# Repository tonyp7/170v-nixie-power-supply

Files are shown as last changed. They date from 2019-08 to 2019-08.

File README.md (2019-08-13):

# 170v-nixie-power-supply
170V, LT3757 based nixie power supply **open source hardware**.

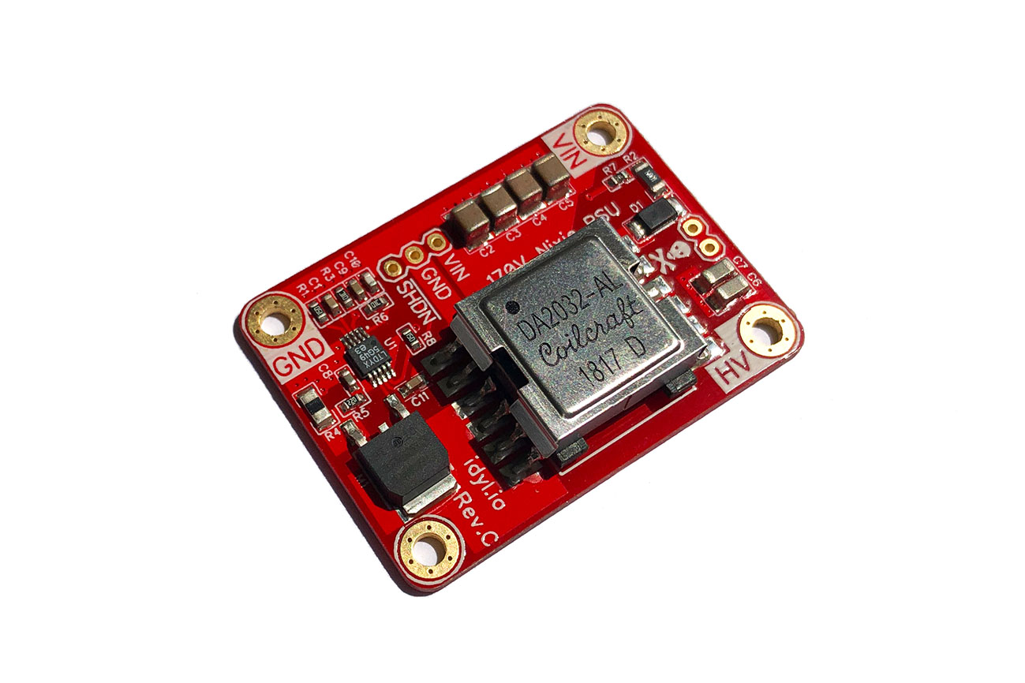
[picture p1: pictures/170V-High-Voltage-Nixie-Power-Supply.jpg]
Assembled PCB


These pages contains everything you need to create a high efficiency nixie power supply.

# Repository Structure

* bom: the bill of materials for the power supply.
* gerber: gerber to generate the PCB for the power supply, together with a render.
* pictures: just some pics of the board.
* schematics: available as png or pdf format.

# Links

* Tindie Store https://www.tindie.com/products/tonyp7/170v-high-voltage-nixie-power-supply/
* Hackaday project page https://hackaday.io/project/162301-high-voltage-nixie-power-supply
* Personal pages https://idyl.io

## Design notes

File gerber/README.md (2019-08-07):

# Gerber Files

These gerber files will allow you to create a new PCB; as shown below:

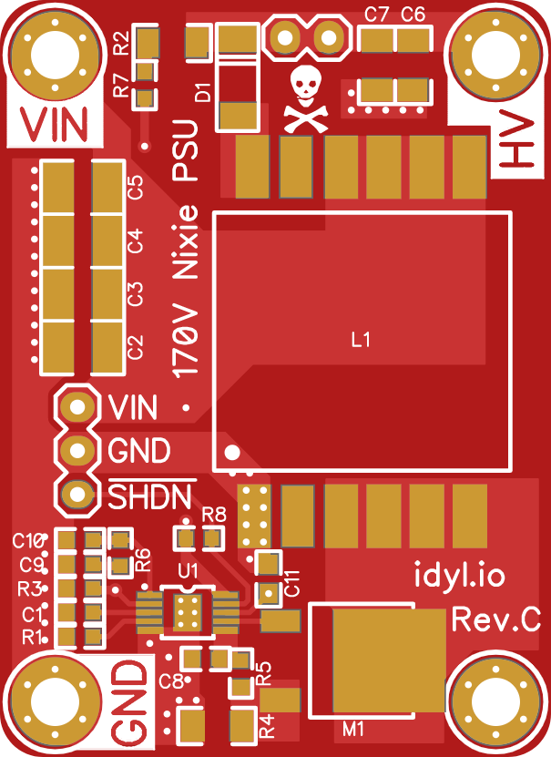
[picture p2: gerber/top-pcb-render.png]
PCB Render


Render courtesy of tracespace.io

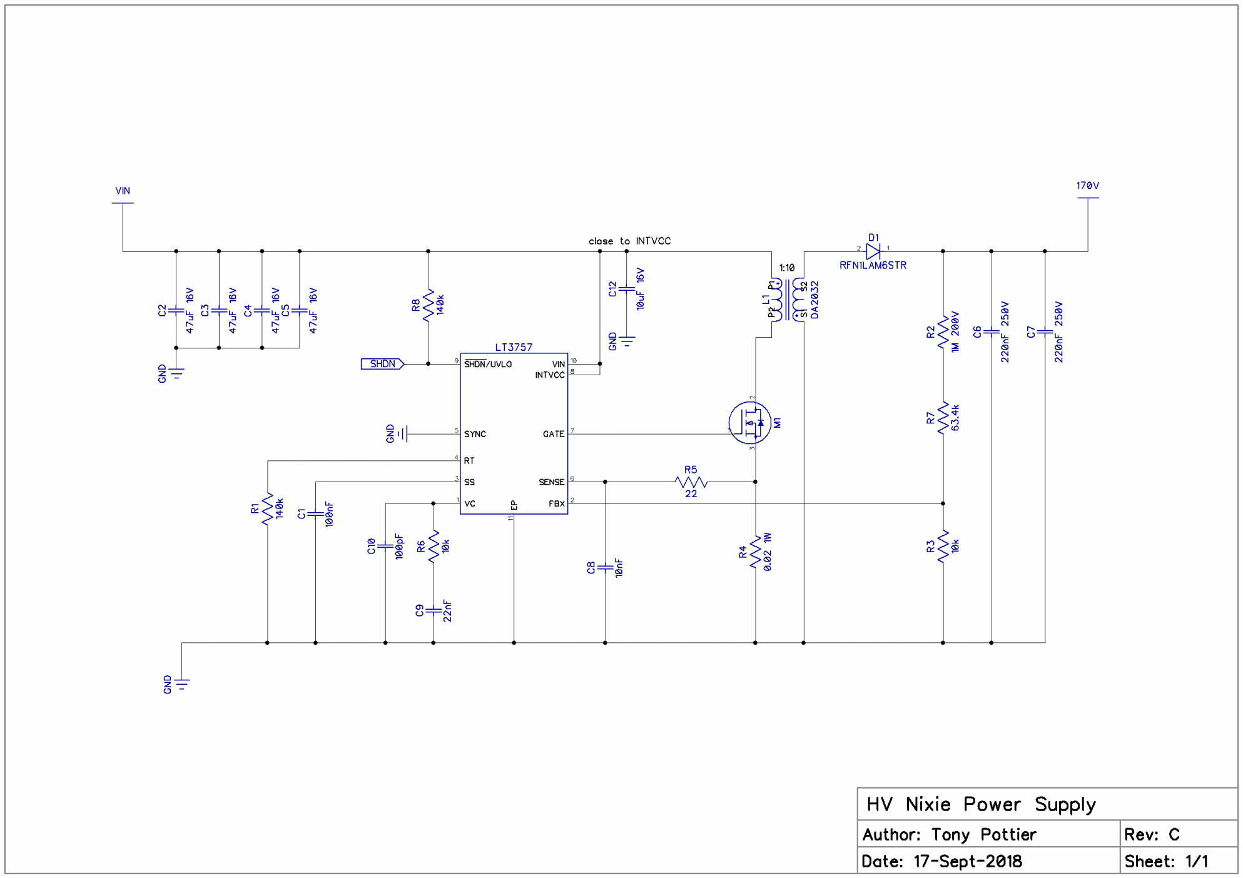
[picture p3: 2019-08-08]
schematics/lt3757-170-power-supply-schematics.png

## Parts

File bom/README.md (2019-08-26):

# Bill of Materials

In this folder you will find the BOM for the PSU, in various formats: CSV, Excel and OpenDocument Spreadsheet. Below in markdown format:

| Ref Desc | Quantity | Manufacturer | Manufacturer Part Number | Description | Package | Type | Comment |
| --- | --- | --- | --- | --- | --- | ---- | --- |
| C1 | 1 | Yageo | CC0603KRX7R9BB104 | 0.1µF ±10% 50V MLCC X7R 0603 | 0603 | SMD |  |
| C2, C3, C4, C5 | 4 | Taiyo Yuden | EMK325BJ476MM-T | 47µF ±20% 16V MLCC X5R 1210 | 1210 | SMD | Use 25V if you can to increase VIN range |
| C6, C7 | 2 | TDK | C3216X7T2E224K160AA | 0.22µF ±10% 250V MLCC X7T 1206 | 1206 | SMD | Must be 250V+ rated |
| C8 | 1 | Yageo | AC0603KRX7R9BB103 | 0.01µF ±10% 50V MLCC X7R 0603 | 0603 | SMD |  |
| C9 | 1 | Yageo | CC0603KRX7R9BB223 | 0.022µF ±10% 50V MLCC X7R 0603 | 0603 | SMD |  |
| C10 | 1 | Yageo | CC0603KRX7R9BB101 | 100pF ±10% 50V MLCC X7R 0603 | 0603 | SMD |  |
| C11 | 1 | Yageo | CC0603MRX5R7BB106 | 10µF ±20% 16V MLCC X5R 0603 | 0603 | SMD |  |
| D1 | 1 | ROHM | RFN1LAM6STR | Diodes - General Purpose, Power, Switching 600V VR 0.8A IO SOD-128; PMDTM | SOD128 | SMD | ES1G works well if you'd like a more commonly available part |
| L1 | 1 | Coilcraft | DA2032-ALB | Flyback Transformer 1:10 10uH | DA2032 | SMD |  |
| M1 | 1 | Infineon | IRLR3110ZTRPBF | HEXFET N-CH 100V 42A DPAK TO-252-3 | TO-252-3 | SMD | Any fast switching MOSFET works but this one is particularly good |
| R1, R8 | 2 | Yageo | RC0603FR-07140KL | Resistor SMD 140K 1% 1/10W 0603 | 0603 | SMD |  |
| R2 | 1 | Yageo | MCR18EZPD1004 | Resistor SMD 1M 0.5% 1/8W 1206 | 1206 | SMD |  |
| R3, R6 | 2 | Yageo | RC0603FR-0710KL | Resistor SMD 10K 1% 1/10W 0603 | 0603 | SMD |  |
| R4 | 1 | Yageo | PE1206FRF470R02L | Resistor Current Sense SMD 0.02R 1% 1W 1206 | 1206 | SMD | Current limiting resistor 0.02 1W is a must for stability |
| R5 | 1 | Yageo | RC0603FR-0722RL | Resistor SMD 22R 1% 1/10W 0603 | 0603 | SMD |  |
| R7 | 1 | Yageo | RC0603FR-0763K4L | Resistor SMD 63.4K 1% 1/10W 0603 | 0603 | SMD | 59K-66K5 works well. |
| U1 | 1 | Linear | LT3757EMSE#PBF | LT3757 Switching Voltage Regulators Boost, Fly, SEPIC & Inv Cntr | MSOP10 | SMD | Any LT3757 or LT3757A variants in MSOP10 will work |

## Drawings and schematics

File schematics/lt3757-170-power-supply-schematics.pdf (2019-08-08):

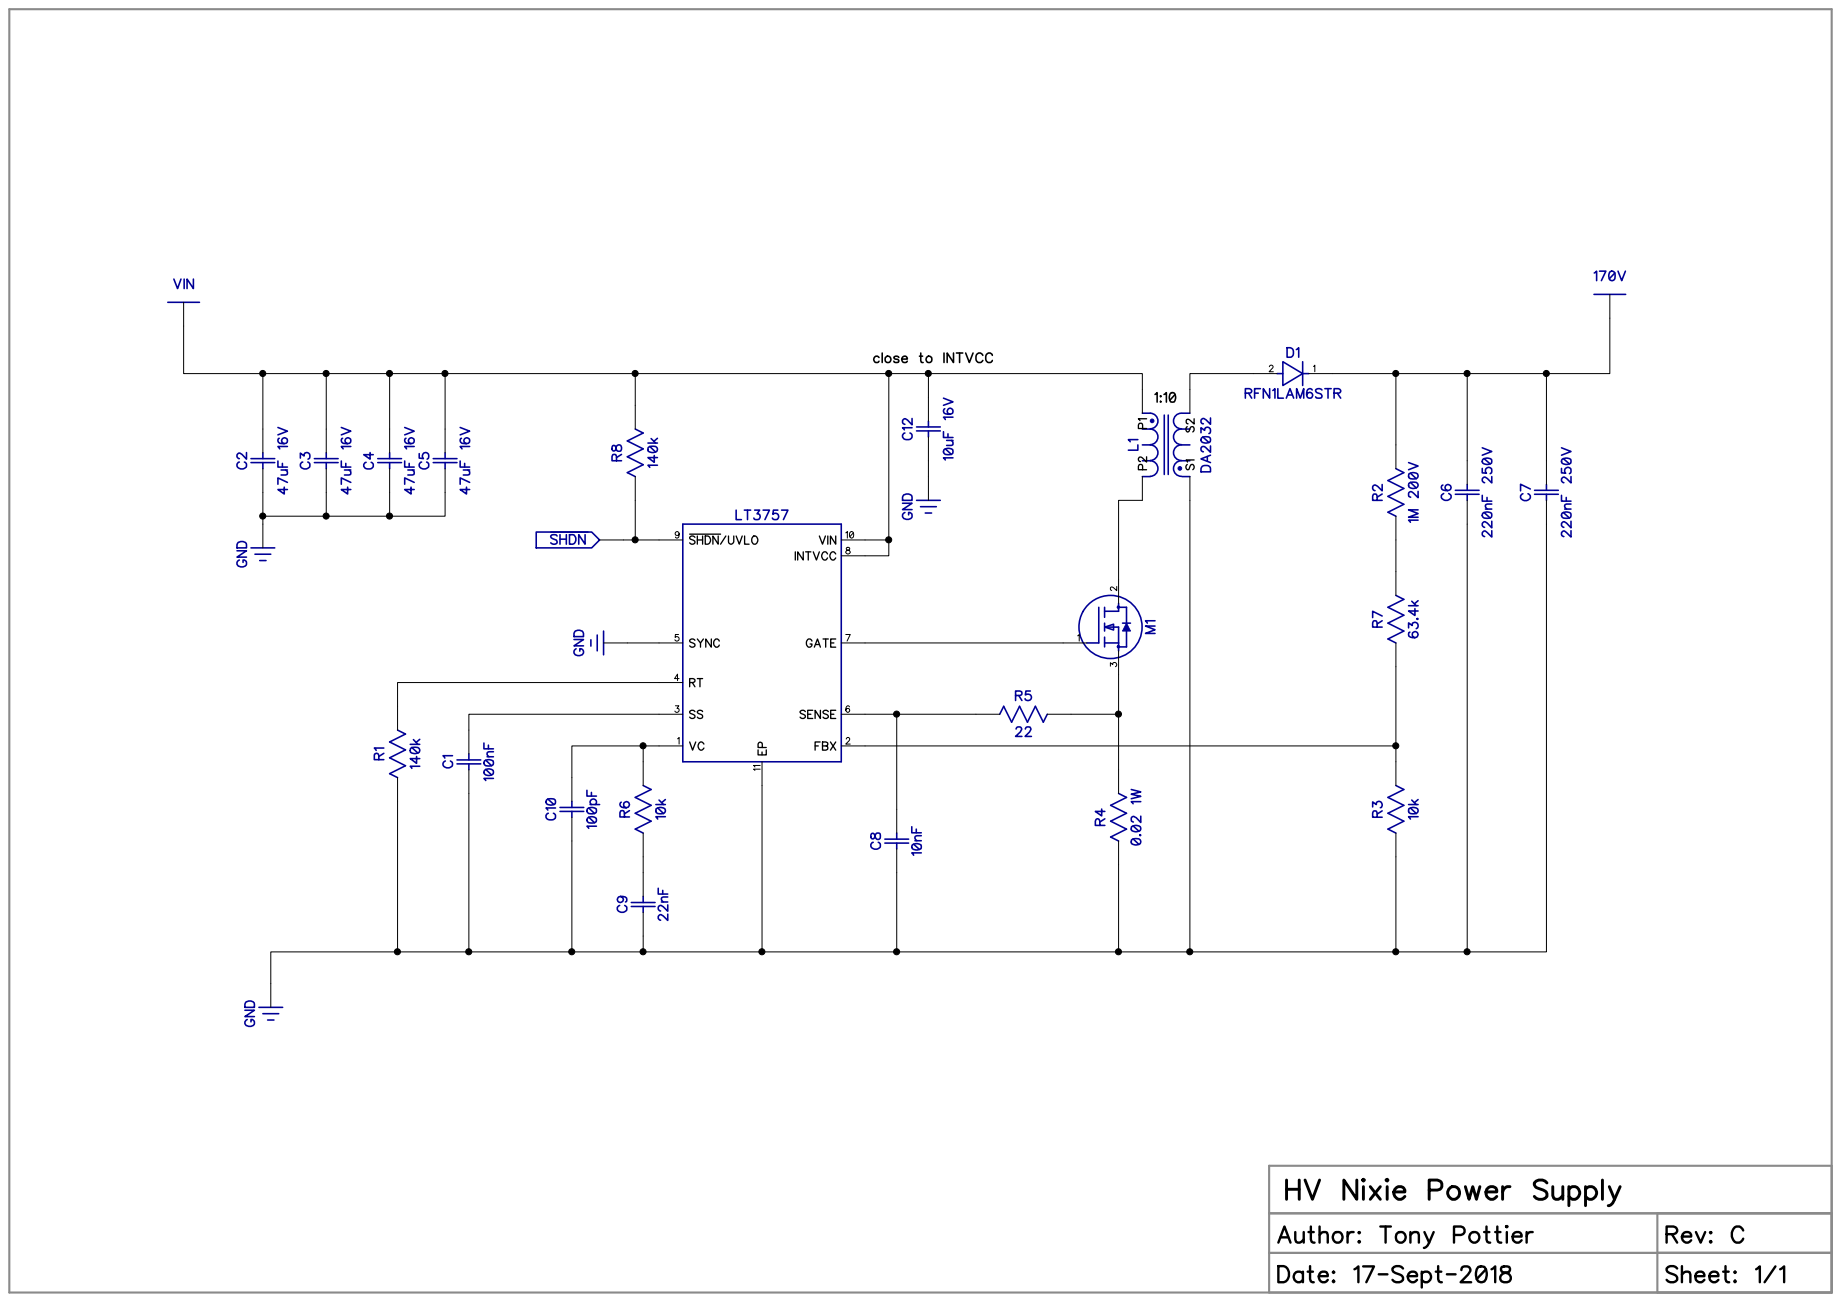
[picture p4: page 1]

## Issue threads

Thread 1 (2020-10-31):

Any possible alternatives to Coilcraft DA2032-ALB?

Fxlr8, 2020-10-31:
Hi, Tony, thanks for a great design. I want to use it in my project, but those coils are rather exotic. Сompanies like JLCPCB or LCSC just don't have it. Can it be replaced with something more popular?

tonyp7, 2020-11-08:
You can replace it but you'll need a 1:10 ~10uH transformer.

They are not very common and some other parts you may find typically are wired in reverse (that is to say they are more a 10:1 transformer and can't handle the high current on the low side)

There are importunately no such thing as "popular part" when it comes to transformers.

Fxlr8, 2020-11-09:
Ok, got it. I think I will order Coilcraft's transformers then. Want to be 100% sure that everything works as expected.

Closed 2020-11-09.

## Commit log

2019-08-06 uploaded BOM
    [bom.csv, bom.ods, bom.xlsx]
2019-08-07 added gerber
    [Through.drl, lt3757_nixie_power_supply.Board.gbr, lt3757_nixie_power_supply.BoardOutline.gbr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]
2019-08-07 pcb render
2019-08-08 added schematics
2019-11-17 added centroid file for assembly
    [centroid.csv]
